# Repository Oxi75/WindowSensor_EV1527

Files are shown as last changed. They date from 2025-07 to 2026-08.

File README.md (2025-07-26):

# WindowSensor_EV1527

This project enables the integration of affordable 433 MHz window sensors and push buttons into the **homee** smart home system via **vhih**.

## Hardware

- **ESP32** microcontroller
- **EV1527** 433 MHz receiver module

## Features

- Receives signals from standard 433 MHz window sensors and push buttons (EV1527 protocol)
- Forwards sensor states to homee via vhih
- Simple configuration through a web interface

## Installation

1. Assemble the hardware according to the schematic (ESP32 + EV1527 receiver).
2. compile and flash the nano firmware [PlatformIO](https://platformio.org/).
3. compile and flash the ESP32 firmware 
4. Connect the device to Wi-Fi and configure it via the web interface.

## Directory Structure

- `src/` – Project source code
- `include/` – Header files
- `data/` – Web interface files (e.g., configuration)
- `examples/` – Example projects
- `doku/` – user manual
- `KiCad/` – Schematics and PCB layout

## Notes

- Further information about integrating with homee and vhih can be found in the documentation and source code.
- License: See [LICENSE](LICENSE)

---

Window and door sensor for homee, based on EV1527 and ESP32.

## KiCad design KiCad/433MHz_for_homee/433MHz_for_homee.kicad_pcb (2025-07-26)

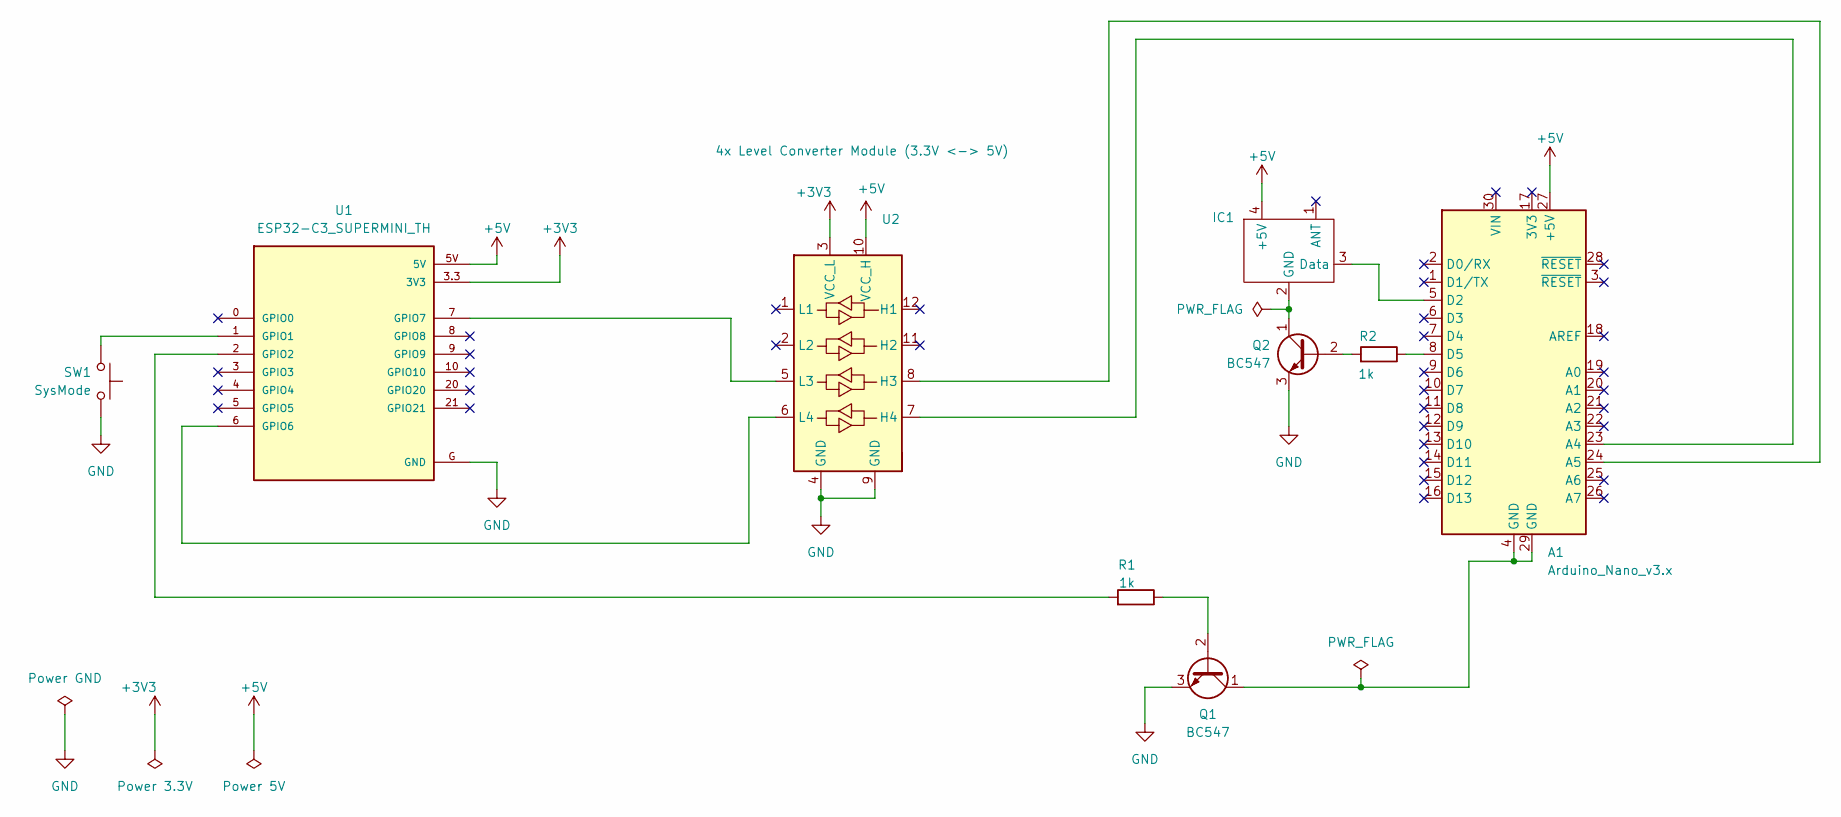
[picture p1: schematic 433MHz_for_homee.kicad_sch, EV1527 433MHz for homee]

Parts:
A1: Arduino_Nano_v3.x; Arduino_Nano
IC1: rxb14_433MHz_module
Q1, Q2: BC547; TO-92_Inline
R1, R2: 1k; R_0805_2012Metric_Pad1.20x1.40mm_HandSolder
SW1: SysMode; PinHeader_1x02_P2.54mm_Vertical
U1: ESP32-C3_SUPERMINI_TH; MODULE_ESP32-C3_SUPERMINI_TH
U2: 4x Level Converter Module (3.3V <-> 5V); LevelConverter_MH

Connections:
+3V3: U1.3.3 (3V3), U2.3 (VCC_L)
+5V: A1.27 (+5V), IC1.4 (+5V), U1.5V, U2.10 (VCC_H)
GND: Q1.3 (E), Q2.3 (E), SW1.1, U1.G (GND), U2.4 (GND), U2.9 (GND)
unnamed: A1.23 (A4), U2.7 (H4)
unnamed: A1.24 (A5), U2.8 (H3)
unnamed: A1.5 (D2), IC1.3 (Data)
unnamed: A1.8 (D5), R2.1
unnamed: IC1.2 (GND), Q2.1 (C)
unnamed: Q1.2 (B), R1.1
unnamed: A1.4 (GND), A1.29 (GND), Q1.1 (C)
unnamed: Q2.2 (B), R2.2
unnamed: SW1.2, U1.1 (GPIO1)
unnamed: R1.2, U1.2 (GPIO2)
unnamed: U1.6 (GPIO6), U2.6 (L4)
unnamed: U1.7 (GPIO7), U2.5 (L3)

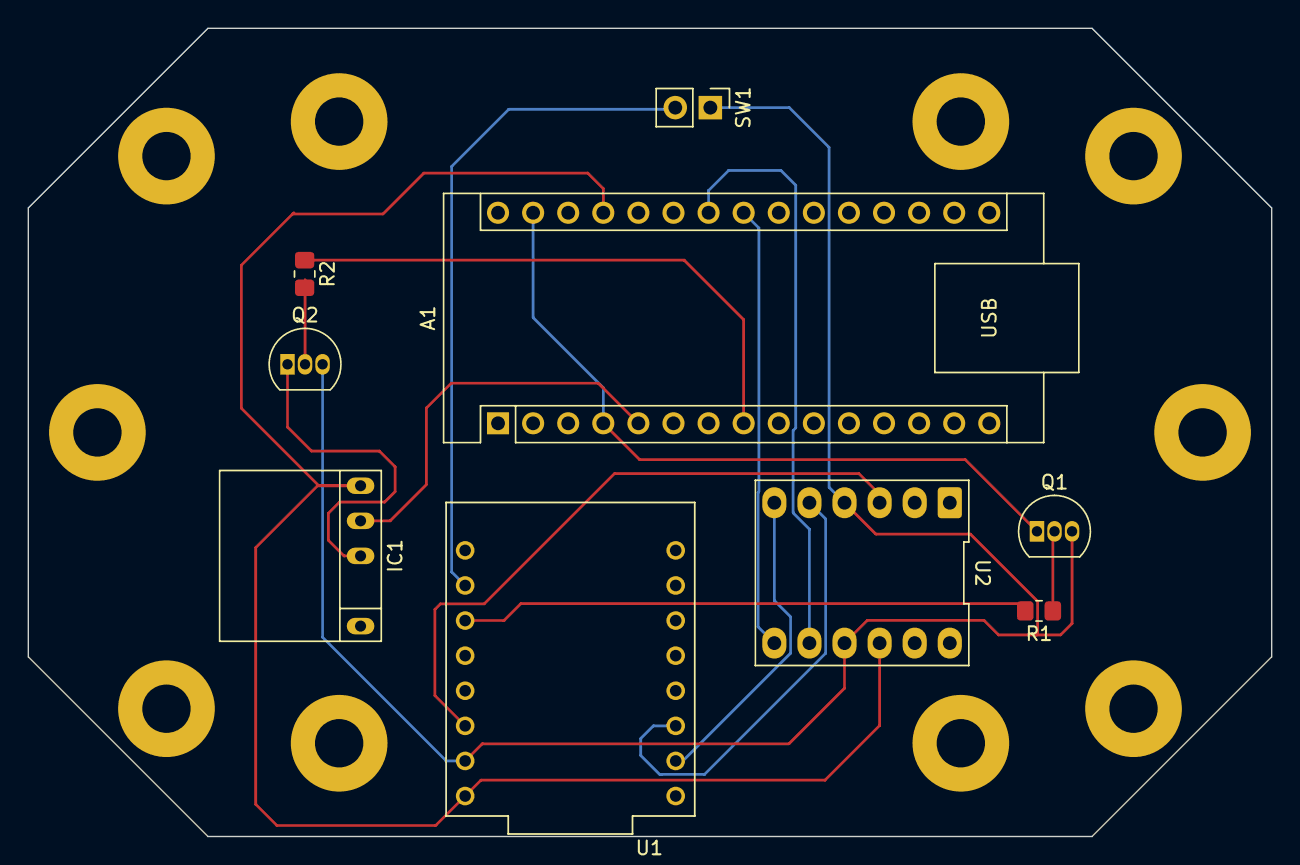
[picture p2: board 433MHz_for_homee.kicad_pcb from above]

Board: 2 copper layers, 90.0 x 58.5 mm, 9 parts (0 on the bottom side), 15 nets.

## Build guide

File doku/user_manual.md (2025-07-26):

# User Manual: Sensor\_EV1527

## 1. Hardware requirements
* Arduino Nano or similar
* ESP32-C3 or similar
* RBX14 433MHz Module
* 2x Level-Converter 3.3V <-> 5V
* 2x BC547
* 2x Resistor 1k
* Push-Button for System mode
* wire (17.3cm) or solid antenna suited for 433MHz
* sensors based on EV1527

 Note that the entire system will be supplied via the USB port of the ESP32. If you use the USB of the Nano it will not work. Only for flashing the Nano firmware you'll need the USB connector of the Nano.

## 2. Software requirements
* `visual studio code` + `platformIO`

### 2. Compiling and flashing
#### 2.1 Arduino firmware
Connect the Arduino via USB to your computer.
Modify the platformio.ini in the following way:  
    &nbsp;&nbsp;&nbsp;[platformio]  
    &nbsp;&nbsp;&nbsp;default_envs = nano  
    &nbsp;&nbsp;&nbsp;;default_envs = esp32-c3  

Build and upload the code.

#### 2.1 ESP32 firmware
Connect the ESP32 via USB to your computer.
Modify the platformio.ini in the following way:  
    &nbsp;&nbsp;&nbsp;[platformio]  
    &nbsp;&nbsp;&nbsp;;default_envs = nano  
    &nbsp;&nbsp;&nbsp;default_envs = esp32-c3  

Build and upload the code.

Upload config.html and index html:
execute `pio run --target uploadfs`in the platformio temrinal.

### 3. Configuration
#### 3.1 general setup
Note: On first startup a config.json file will be generated in the minifs of the ESP32.

Press the systemMode push button during boot of the ESP32 startup. The ESP will enter the setup mode and provides and Access point. 
This are the WiFi data:  
&nbsp;&nbsp;&nbsp;SSID: EV1527 for homee
&nbsp;&nbsp;&nbsp;Password: 12345678
&nbsp;&nbsp;&nbsp;IP: 192.168.4.1  
&nbsp;&nbsp;&nbsp;SubNet-Mask:  255.255.255.0
Note that the WiFi data for the access point cannot be changed!

After you have been connected to your access point you can connect to the WebInterface via your browser by entering http://192.168.4.1.  
It's recommended to use your PC browser since the WebInterface is not responsive and might be difficult to read on mobile devices.

You can enter now your personal WiFi data, configure the sensor address, ...
Be careful uploading html files and firmware. If your upload invalid files it might corrupt your ESP system and you have to flash it again.

#### 3.2 sensor configuration
You can configure up to 32 sensors.  
You must give a name to each sensor. Only use English letters (e.g. "Tuere" instead of "Türe"). Spaces are ok.  
Each sensor must have a unique homee-ID. Unique means in the entire homee-network.  
Each sensor has a unique address. You can get this address from the section `last received signal`. Let the sensor send its signal(s) and get the address and values from there.

Each sensor can be one of the four types:
1. OpenClose-Sensor
2. OneButton-Remote
3. TwoButton-Remote
4. ThreeButton-Remote
5. FourButton-Remote

For the OpenClose-Sensor you can configure a valaue for Open (Window / Door openes), for Close, for Modification Alarm and for a Battery Low warning. Set the Signal value to -1 if there is no such value available for your sensor model.
If you set a delay, the signal will be removed after the given time in seconds.

For the remote button sensors you have to define the following:  
* Value - the value of the sensor button
* Delay - when shall the system automatically switch back to "off"; -1 if the state shall remain
* Mode: - "Toggle" (usually in combination with delay -1); re-trigger (usually in combination with a delay > 0)  
toggle means that the state will remain until the button is pressed again or until the delay time is over  
re-trigger means that pressing the button will start the delay time again

### Screenshots

assebled PCB:
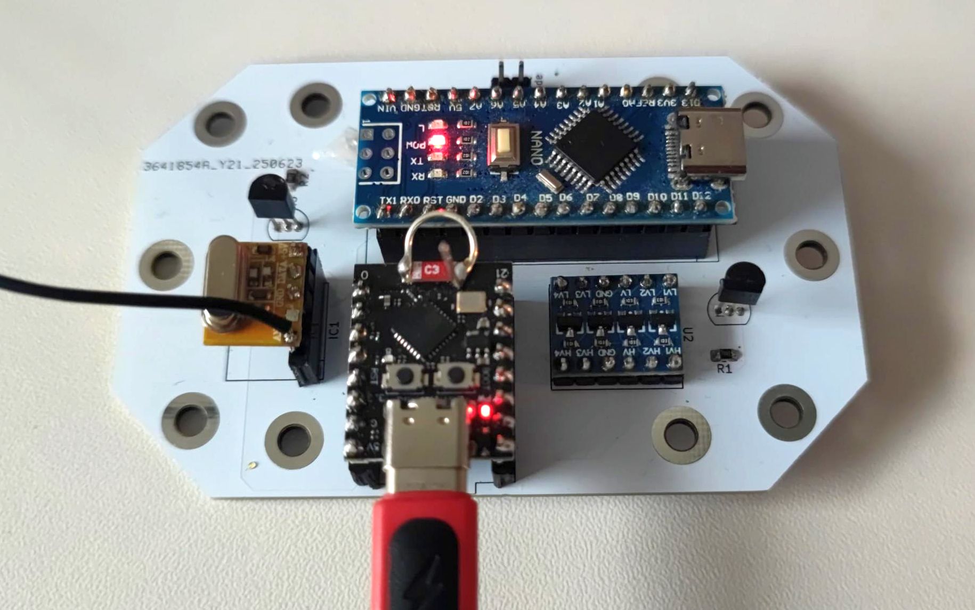
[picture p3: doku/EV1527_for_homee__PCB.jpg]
assebled PCB


fully integraged:
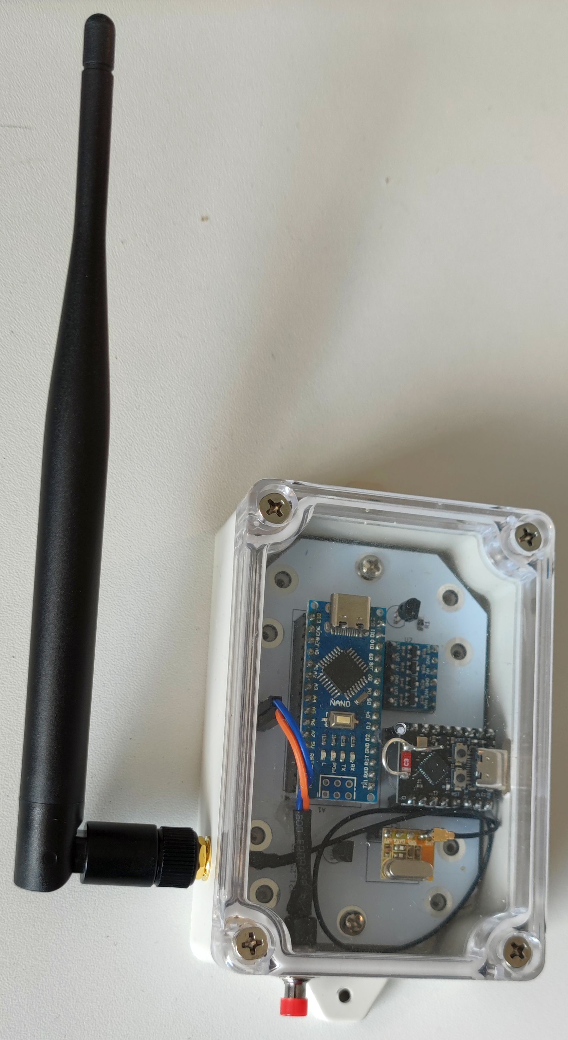
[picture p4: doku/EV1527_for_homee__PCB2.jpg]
fully integrated


used sensors:
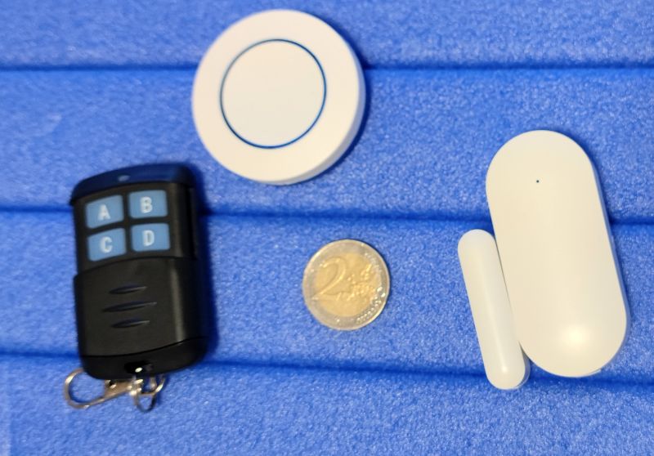
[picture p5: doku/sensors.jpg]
sensors
)

---

For updates and source code, refer to the [GitHub repository](https://github.com/Oxi75/WindowSensor_EV1527).

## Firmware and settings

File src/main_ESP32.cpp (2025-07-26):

/*
  EV1527 Window Sensor Monitor for homee
  
  This program monitors up to 32 window sensors based on the EV1527 chip
  and connects to the homee smart home system.
  The sensor signals are received via I2C and processed to update the homee nodes.
  
  Multiple operation modes:
  1. Configuration mode (AP mode for setup)
  2. Normal mode (sensor monitoring and homee integration)
  
  Hardware: ESP32-C3

  Libraries:
  - homee-api-esp32: https://github.com/Oxi75/homee-api-esp32
*/

#include "global_defines.h"
#include <Arduino.h>
#include <Update.h>
#include <WiFi.h>
#include <ESPAsyncWebServer.h>
#include <Wire.h>
#include <LittleFS.h>
#include "ConfigManager.h"
#include <string>
#include "virtualHomee.hpp"

#define RECEIVER_CHECK_INTERVAL 350             // Interval in ms to check for received signals

String FW_VERSION_STR = String(FW_VERSION_ESP, 2);

#define CANodeProfileOneButtonRemote 20
#define CANodeProfileTwoButtonRemote 24
#define CANodeProfileThreeButtonRemote 25
#define CANodeProfileFourButtonRemote 26

#define CANodeProfileOpenCloseSensor 2000
#define CAAttributeTypeOpenClose 14
#define CAAttributeTypeAlarm 108
#define CAAttributeTypeBatteryLowAlarm 69
#define CAAttributeTypeOnOff 1
#define CAAttributeTypeFirmwareRevision 44
#define CAAttributeTypeBinaryInput 19
#define CAAttributeTypeButtonState 40
#define CAAttributeTypeNone 0

#define AttrID_SnsAddr    0b00100000  //one part of the Attribute ID of homee, the other one is the sensor number
#define AttrID_FwRev      0b01000000  //one part of the Attribute ID of homee, the other one is the sensor number
#define AttrID_Sig1       0b01100000  //one part of the Attribute ID of homee, the other one is the sensor number
#define AttrID_Sig2       0b10000000  //one part of the Attribute ID of homee, the other one is the sensor number
#define AttrID_Sig3       0b10100000  //one part of the Attribute ID of homee, the other one is the sensor number
#define AttrID_Sig4       0b11000000  //one part of the Attribute ID of homee, the other one is the sensor number


const char* AP_SSID = "EV1527 for homee";
const char* AP_PASS = "12345678";
const IPAddress AP_IP(192, 168, 4, 1);
const IPAddress AP_SUBNET(255, 255, 255, 0);
bool isAPMode = false;

ConfigManager config;

// LED related functions
static unsigned long lastBlinkTime = 0;
static const unsigned long blinkInterval = 500; // 500ms Blink-Intervall
static bool ledState = false;

void LED_setup()
{
    pinMode(PIN_LED, OUTPUT);
    digitalWrite(PIN_LED, HIGH); // LED aus (meist ist LOW = an bei ESP8266)
}

void ledOn()
{
    digitalWrite(PIN_LED, LOW); // LED einschalten (LOW = an beim ESP8266)
    ledState = true; // LED-Status setzen
    lastBlinkTime = millis() - blinkInterval - 1; // Zeitstempel aktualisieren
}

void ledOff()
{
    digitalWrite(PIN_LED, HIGH); // LED ausschalten (HIGH = aus beim ESP8266)
    ledState = false; // LED-Status zurücksetzen
    lastBlinkTime = millis() - blinkInterval - 1; // Zeitstempel aktualisieren    
}

void ledToggle()
{
    ledState = !ledState;
    digitalWrite(PIN_LED, ledState ? LOW : HIGH); // LED umschalten
    lastBlinkTime = millis() - blinkInterval - 1; // Zeitstempel aktualisieren
}

void ledBlink()
{
    unsigned long currentMillis = millis();
    if (currentMillis - lastBlinkTime >= blinkInterval)
    {
        lastBlinkTime = currentMillis;
        ledState = !ledState;
        digitalWrite(PIN_LED, ledState ? LOW : HIGH); // LED umschalten
    }
}

//Sensor Daten
struct LastSignal
{
    String sensorAddress;
    String sensorData;
    String binary;
};

// Globale Variable mit dem letzten Signal
LastSignal lastSignal = {
    .sensorAddress = "-------",
    .sensorData = "-",
    .binary = "------------------------",
};
 

//WiFi realted functions
AsyncWebServer server(80);

unsigned long lastWifiCheckTime = 0;
const unsigned long wifiCheckInterval = 30000; // Alle 30 Sekunden WLAN prüfen
const unsigned long wifiMaxAttempts = 20; // 
static uint32_t wifiConnectAttempts = 0; // Anzahl der Versuche, sich mit dem WLAN zu verbinden
static bool WiFi_reconnect = false;  //system is in reconnection
String configBodyContent = "";  //variable to hold the HTML content of the config page

IPAddress IPAddressFromString(const String& str) {
  IPAddress ip;
  if (!ip.fromString(str)) {
    Serial.println("[IP] Invalid IP string: " + str);
    return IPAddress(0, 0, 0, 0);
  }
  return ip;
}

void startWiFi() 
{ 
  pinMode(PIN_SYSMODE, INPUT_PULLUP);
  isAPMode = digitalRead(PIN_SYSMODE) == LOW;

  if (isAPMode)
  {
    Serial.println("[BOOT] Starting in AccessPoint mode");
    WiFi.softAPConfig(AP_IP, AP_IP, AP_SUBNET);
    WiFi.softAP(AP_SSID, AP_PASS);
    Serial.println("[AP] SSID: " + String(AP_SSID));
    Serial.println("[AP] Password: " + String(AP_PASS));
    Serial.println("[AP] IP: " + WiFi.softAPIP().toString());
  }
  else
  {
    Serial.println("[BOOT] Starting in Standard mode");
    WiFi.config(
      IPAddressFromString(config.clientIP),
      IPAddressFromString(config.gatewayIP),
      IPAddressFromString(config.subnet)
    );
    WiFi.begin(config.ssid.c_str(), config.password.c_str());

    int retries = 0;
    while (WiFi.status() != WL_CONNECTED && retries < 20)
    {
      ledToggle(); // LED blinken lassen, um den Verbindungsversuch anzuzeigen
      delay(500);
      Serial.print(".");
      retries++;
    }

    if (WiFi.status() != WL_CONNECTED) {
      Serial.println("\n[WIFI] Connection failed. Restarting...");
      ESP.restart();
    }

    Serial.println("\n[WIFI] Connected. IP: " + WiFi.localIP().toString());
  }

  ledOn(); // alten Zustand der LED wiederherstellen
}


void WiFi_check(bool restart = true)
{
    if ((millis() - lastWifiCheckTime >= wifiCheckInterval) || (WiFi_reconnect))
    {
        lastWifiCheckTime = millis();
    
        // Bei Verbindungsverlust erneut verbinden
        if (WiFi.status() != WL_CONNECTED) 
        {
            WiFi_reconnect = true;
            Serial.println("WiFi connection lost. Reconnecting...");
            ledToggle(); // LED blinken lassen, um den Verbindungsverlust anzuzeigen
            WiFi.reconnect();
            wifiConnectAttempts++;
            delay(500);
         }

        if (WiFi.status() == WL_CONNECTED)
        {
            WiFi_reconnect = false;
            wifiConnectAttempts = 0; // WLAN-Verbindung erfolgreich
            ledOff(); // LED ausschalten, wenn WLAN verbunden ist
        }

        if (wifiConnectAttempts >= wifiMaxAttempts) 
        {
            Serial.println("Failed to reconnect to WiFi. Restarting ESP...");
            ESP.restart(); // ESP32 zurücksetzen, wenn keine Verbindung hergestellt werden kann
        }    
    }
}


// Homee related functions
virtualHomee vhih;

void homee_setup()
{
  for (int sns = 0; sns < MAX_SENSORS; sns++)
  {
    if ((config.sensors[sns].name == "") || (!config.sensors[sns].active) || (config.sensors[sns].homeeID == 0))
    {
      Serial.printf("[HOMEE] Sensor %d is not active or has no name or invalid homeeID -> skipping.\n", sns);      
      continue;
    }

    if ((config.RTData[sns].btnCnt > 4) || (config.RTData[sns].btnCnt < 1))
    {
      Serial.printf("[HOMEE] Sensor %d has invalid button count %d or an invalid type '%s' -> skipping.\n", sns, config.RTData[sns].btnCnt, config.sensors[sns].type.c_str());
      continue;
    }
/*
    if ((config.sensors[sns].type != "OpenClose Sensor") 
     && (config.sensors[sns].type != "OneButton Remote") && (config.sensors[sns].type != "TwoButton Remote")
     && (config.sensors[sns].type != "ThreeButton Remote") && (config.sensors[sns].type != "FourButton Remote"))
    {
      Serial.printf("[CONFIG] Sensor %d has an invalid type '%s' -> skipping.\n", sns, config.sensors[sns].type.c_str());
      continue;
    }
*/

    Serial.printf("[HOMEE] setup sensor %s with address 0x%05x as %s at homee device with ID %d\n", config.sensors[sns].name.c_str(), config.sensors[sns].address, config.sensors[sns].type.c_str(), config.sensors[sns].homeeID);

    //all checks done, now new add the new sensor with all its attributes to homee    
    node *n;
    nodeAttributes *na, *naAddr, *naFW;

    naAddr = new nodeAttributes(CAAttributeTypeNone);  //
    naAddr->setName("Sensor Address");
    naAddr->setId(AttrID_SnsAddr | sns);
    naAddr->setUnit("0x" + String(config.sensors[sns].address, HEX));  //set unit to the address in hex format
    naAddr->setMinimumValue(0);
    naAddr->setMaximumValue(999999999999); 
    naAddr->setCurrentValue(config.sensors[sns].address);
    naAddr->setEditable(false);
    naAddr->setCallback(nullptr);

    naFW = new nodeAttributes(CAAttributeTypeFirmwareRevision); 
    naFW->setName("Firmware Version");
    naFW->setId(AttrID_FwRev | sns); //unique ID for each sensor
    naFW->setUnit("");  
    naFW->setMinimumValue(0.0);
    naFW->setMaximumValue(1000.0); 
    naFW->setCurrentValue(FW_VERSION_ESP);
    naFW->setEditable(false);
    naFW->setCallback(nullptr);

    if (config.RTData[sns].OCSensor)
    {
      n = new node(config.sensors[sns].homeeID, CANodeProfileOpenCloseSensor, config.sensors[sns].name);     
      n->AddAttributes(naAddr);     //set attribute Sensor Address to node
      n->AddAttributes(naFW);       //set attribute Firmware to node

      //Attribut Status
      na = new nodeAttributes(CAAttributeTypeOpenClose);  //open / closed state
      na->setName("Status");
      na->setId(AttrID_Sig1 | sns); //unique ID for each sensor        
      na->setMinimumValue(0);
      na->setMaximumValue(1); 
      na->setCurrentValue(0);
      na->setCallback(nullptr);
      na->setEditable(false);
      n->AddAttributes(na);       //set attribute to node

      //Attribut Alarm
      na = new nodeAttributes(CAAttributeTypeAlarm);  //CAAttributeTypeAlarm
      na->setName("Alarm");
      na->setId(AttrID_Sig3 | sns);   //unique ID for each sensor
      na->setUnit("");  
      na->setMinimumValue(0);
      na->setMaximumValue(1); 
      na->setCurrentValue(0);     //default value
      na->setEditable(false);
      na->setCallback(nullptr);
      n->AddAttributes(na);       //set attribute to node

      //Attribut Batterie
      na = new nodeAttributes(CAAttributeTypeBatteryLowAlarm);
      na->setName("Battery Status");
      na->setId(AttrID_Sig4 | sns); //unique ID for each sensor
      na->setUnit("");
      na->setMinimumValue(0);  //0 = Battery OK, 1 = Battery low
      na->setMaximumValue(1); 
      na->setCurrentValue(0);  //default value
      na->setEditable(false);
      na->setCallback(nullptr);
      n->AddAttributes(na);       //set attribute to node
    }
    else  //must be an x-button remote
    {
      uint32_t vhihProfile = 0;
      if (config.RTData[sns].btnCnt == 1)  vhihProfile = CANodeProfileOneButtonRemote;
      else if (config.RTData[sns].btnCnt == 2) vhihProfile = CANodeProfileTwoButtonRemote;
      else if (config.RTData[sns].btnCnt == 3) vhihProfile = CANodeProfileThreeButtonRemote;
      else if (config.RTData[sns].btnCnt == 4) vhihProfile = CANodeProfileFourButtonRemote;

      n = new node(config.sensors[sns].homeeID, vhihProfile, config.sensors[sns].name);
      n->AddAttributes(naAddr);     //set attribute Sensor Address to node
      n->AddAttributes(naFW);       //set attribute Firmware to node


      //Attribut for first Button
      na = new nodeAttributes(CAAttributeTypeButtonState);  //open / closed state
      na->setName("Status Button1");
      na->setId(AttrID_Sig1 | sns); //unique ID for each sensor        
      na->setMinimumValue(0);
      na->setMaximumValue(1); 
      na->setCurrentValue(0);
      na->setCallback(nullptr);
      na->setEditable(false);
      n->AddAttributes(na);       //set attribute to node

      if (config.RTData[sns].btnCnt >= 2)
      {
        //Attribut Status Button2
        na = new nodeAttributes(CAAttributeTypeButtonState);  //open / closed state
        na->setName("Status Button2");
        na->setId(AttrID_Sig2 | sns); //unique ID for each sensor        
        na->setMinimumValue(0);
        na->setMaximumValue(1); 
        na->setCurrentValue(0);
        na->setCallback(nullptr);
        na->setEditable(false);
        n->AddAttributes(na);       //set attribute to node
      }


      if (config.RTData[sns].btnCnt >= 3)
      {
        //Attribut Status Button3
        na = new nodeAttributes(CAAttributeTypeButtonState);  //open / closed state
        na->setName("Status Button3");
        na->setId(AttrID_Sig3 | sns); //unique ID for each sensor        
        na->setMinimumValue(0);
        na->setMaximumValue(1); 
        na->setCurrentValue(0);
        na->setCallback(nullptr);
        na->setEditable(false);
        n->AddAttributes(na);       //set attribute to node
      }

      if (config.RTData[sns].btnCnt == 4)
      {
        //Attribut Status Button4
        na = new nodeAttributes(CAAttributeTypeButtonState);  //open / closed state
        na->setName("Status Button4");
        na->setId(AttrID_Sig4 | sns); //unique ID for each sensor        
        na->setMinimumValue(0);
        na->setMaximumValue(1); 
        na->setCurrentValue(0);
        na->setCallback(nullptr);
        na->setEditable(false);
        n->AddAttributes(na);       //set attribute to node
      }
    }

    vhih.addNode(n); //add the new node to homee
  }

  vhih.start();  //start homee API

  Serial.println("Homee configured");
  delay(1000);  
}


static double lastValue = 1;
void homee_updateValues(uint32_t snsNo)
{  
  Serial.printf("update homee values for Sensor No %d (%s)\n", snsNo, config.sensors[snsNo].type.c_str());

  nodeAttributes *na;
  
  if ((config.RTData[snsNo].btnCnt >= 4) && (config.RTData[snsNo].signal4))
  {
    na = vhih.getAttributeById(AttrID_Sig4 | snsNo);
    na->setCurrentValue(config.RTData[snsNo].signal4_val);
    config.RTData[snsNo].signal4 = false;
    if (na) vhih.updateAttributeValue(na, na->getCurrentValue());
    delay(200);
    yield();
  } 

  if ((config.RTData[snsNo].btnCnt >= 3) && (config.RTData[snsNo].signal3))
  {
    na = vhih.getAttributeById(AttrID_Sig3 | snsNo);
    na->setCurrentValue(config.RTData[snsNo].signal3_val);
    config.RTData[snsNo].signal3 = false;
    if (na) vhih.updateAttributeValue(na, na->getCurrentValue());
    delay(200);
    yield();
  } 

  if ((config.RTData[snsNo].btnCnt >= 2) && (config.RTData[snsNo].OCSensor == false) && (config.RTData[snsNo].signal2))
  {
    na = vhih.getAttributeById(AttrID_Sig2 | snsNo);
    na->setCurrentValue(config.RTData[snsNo].signal2_val);
    config.RTData[snsNo].signal2 = false;
    if (na) vhih.updateAttributeValue(na, na->getCurrentValue());
    delay(200);
    yield();
  } 

  if ((config.RTData[snsNo].btnCnt >= 1) && (config.RTData[snsNo].OCSensor == false) && (config.RTData[snsNo].signal1))
  {
    na = vhih.getAttributeById(AttrID_Sig1 | snsNo);
    na->setCurrentValue(config.RTData[snsNo].signal1_val);
    config.RTData[snsNo].signal1 = false;
    if (na) vhih.updateAttributeValue(na, na->getCurrentValue());
    delay(200);
    yield();
  } 

  if ((config.RTData[snsNo].OCSensor) && (config.RTData[snsNo].signal1))
  {
    na = vhih.getAttributeById(AttrID_Sig1 | snsNo);
    na->setCurrentValue(config.RTData[snsNo].signal1_val);
    config.RTData[snsNo].signal1 = false;
    if (na) vhih.updateAttributeValue(na, na->getCurrentValue());
    delay(200);
    yield();
  } 

} 





/// ****************************************************
/// @brief Check for received signals and update sensor data accordingly.
/// @param HomeeEnabled 
/// ****************************************************
void Receiver_setup()
{
  pinMode(PIN_RECEIVER_PWR, OUTPUT);    // set the receiver power pin as output
  digitalWrite(PIN_RECEIVER_PWR, LOW); // switch off the receiver power
  delay(500); // wait for the receiver to stabilize
  digitalWrite(PIN_RECEIVER_PWR, HIGH); // switch on the receiver power
  delay(2000); // wait for the receiver to stabilize

  Wire.begin(PIN_SDA, PIN_SCL);

  Serial.println("[Receiver] setup complete.");
}


// Signal related functions
uint32_t Receiver_getSignal()
{
  uint32_t sensorData = 0;

  Wire.requestFrom(I2C_SLAVE_ADDRESS, 4); //read 4 bytes from the I2C slave device

  if (Wire.available() >= 4)
  {
      sensorData  = Wire.read();
      sensorData |= Wire.read() << 8;
      sensorData |= Wire.read() << 16;
      sensorData |= Wire.read() << 24;        
  }
  else sensorData = DUMMY_CODE_E; // Rückgabe eines Dummy-Wertes, wenn nicht genügend Daten verfügbar sind

//  Serial.printf("Receiver_getSignal(): Received signal: 0x%08x\n", sensorData);

  return sensorData; 
}

void Receiver_check(bool HomeeEnabled)
{
  static bool firstCall = true;
  if (firstCall)
  {
    Serial.print("Receiver_check() for the first time.");
    if (HomeeEnabled) Serial.println(" Homee is enabled.");
    else Serial.println(" Homee is disabled.");
    firstCall = false;
  }

  uint32_t snsAddr = 0;       
  uint32_t snsValue = 0;
  uint32_t now = millis();    // current timestamp
  bool validSignal = false;   // Flag to check if a valid signal was received

  uint32_t sensorData = Receiver_getSignal(); // Lese die Signaldaten von Arduino
  
//  if (sensorData == DUMMY_CODE_F) Serial.println("Receiver_check(): Watchdog-Signal received, no sensor data available.");
//  else if (sensorData == DUMMY_CODE_0) Serial.println("Receiver_check(): FiFo empty, no sensor data available.");
//  else Serial.printf("Receiver_check(): Received signal: 0x%08x\n", sensorData);
  now = millis();                                     // update the timestamp of the last received, valid signal

  if (((sensorData != DUMMY_CODE_0) && (sensorData != DUMMY_CODE_F) && (sensorData != DUMMY_CODE_E)))
  {
    ledOn();                                            // Switch on the LED to indicate signal reception
    validSignal = true;                                 // signal is valid, so set the flag to true

    lastSignal.binary = String(sensorData, BIN);        // convert the sensor data to binary string

    snsValue = sensorData & 0x000000F;                  // ectract the lower 4 bit as value
    lastSignal.sensorData = String(snsValue, DEC);      

    snsAddr = (sensorData >> 4) & 0xFFFFF;              // extract the sensor address from the upper 20 bits
    lastSignal.sensorAddress = String(snsAddr, HEX);    
    lastSignal.sensorAddress.toUpperCase();
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
void loop()
{ 
  static bool firstCall = true;
  if (firstCall)
  {
    Serial.println("Enter control loop for the first time.");
    firstCall = false;
  }

  if (!isAPMode) WiFi_check();

  if ( millis() - lastReceiverCheck >= RECEIVER_CHECK_INTERVAL) // Check receiver every 100ms
  {
//    Receiver_check(!isAPMode); // Check for received signals and update sensor data
    Receiver_check(true); // Check for received signals and update sensor data
    lastReceiverCheck = millis(); // Update the last check time
  }

  yield();  //delay is not allowed here, because homee connection would become unstable
}

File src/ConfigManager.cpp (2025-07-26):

#include "ConfigManager.h"
#include <LittleFS.h>
#include <ArduinoJson.h>

ConfigManager::ConfigManager()
{
  uint32_t now = millis();

  for (uint32_t i = 0; i < MAX_SENSORS; i++)
  {
    RTData[i].signal1_TS = now - 5000; // Set initial timestamps to 5 seconds ago
    RTData[i].signal2_TS = now - 5000; // Set initial timestamps to 5 seconds ago 
    RTData[i].signal3_TS = now - 5000; // Set initial timestamps to 5 seconds ago
    RTData[i].signal4_TS = now - 5000; // Set initial timestamps to 5 seconds ago
    RTData[i].signal1 = false; // Initialize signal1 to false
    RTData[i].signal2 = false; // Initialize signal2 to false
    RTData[i].signal3 = false; // Initialize signal3 to false
    RTData[i].signal4 = false; // Initialize signal4 to false
  }
}

bool ConfigManager::load()
{
  if (!LittleFS.exists(CONFIG_FILE)) {
    Serial.println("[CONFIG] config.json missing – using defaults");
    return false;
  }

  File f = LittleFS.open(CONFIG_FILE, "r");
  if (!f) return false;

  DynamicJsonDocument doc(16384);
  DeserializationError err = deserializeJson(doc, f);
  f.close();
  if (err) {
    Serial.println("[CONFIG] Parse error – using defaults");
    return false;
  }

  cfgInSTA = doc["system"]["cfgInSTA"] | false;
  cfgInStandardMode = doc["system"]["cfgInStandardMode"] | false;  
  ssid     = doc["wifi"]["ssid"] | "";
  password = decrypt(doc["wifi"]["pwX"] | "");
  clientIP  = doc["wifi"]["ip"] | "192.168.1.100";
  gatewayIP  = doc["wifi"]["gw"] | "192.168.1.1";
  subnet   = doc["wifi"]["mask"] | "255.255.255.0";

  JsonArray arr = doc["sensors"].as<JsonArray>();
  int i = 0;
  for (JsonObject s : arr)
  {
    if (i >= MAX_SENSORS) break;
    sensors[i].active   = s["active"] | false;
    sensors[i].name     = s["name"] | "";
    sensors[i].homeeID  = s["homeeID"] | 0;
    sensors[i].type     = s["type"] | "OpenClose";
    sensors[i].address  = s["address"] | 0;
    
    // Load new signal configuration
    sensors[i].signal1  = s["signal1"] | 0;
    sensors[i].signal2  = s["signal2"] | 0;
    sensors[i].signal3  = s["signal3"] | 0;
    sensors[i].signal4  = s["signal4"] | 0;

    // Load new mode configuration
    sensors[i].toggle1 = s.containsKey("toggle1") ? s["toggle1"] | true : true; // Default to true if not present
    sensors[i].toggle2 = s.containsKey("toggle2") ? s["toggle2"] | true : true; // Default to true if not present
    sensors[i].toggle3 = s.containsKey("toggle3") ? s["toggle3"] | true : true; // Default to true if not present
    sensors[i].toggle4 = s.containsKey("toggle4") ? s["toggle4"] | true : true; // Default to true if not present    

    // Load delay configuration - handle NaN values properly
    if (s.containsKey("delay1") && !s["delay1"].isNull()) {
      sensors[i].delay1 = s["delay1"];
    } else {
      sensors[i].delay1 = NAN;
    }
    if (s.containsKey("delay2") && !s["delay2"].isNull()) {
      sensors[i].delay2 = s["delay2"];
    } else {
      sensors[i].delay2 = NAN;
    }
    if (s.containsKey("delay3") && !s["delay3"].isNull()) {
      sensors[i].delay3 = s["delay3"];
    } else {
      sensors[i].delay3 = NAN;
    }
    if (s.containsKey("delay4") && !s["delay4"].isNull()) {
      sensors[i].delay4 = s["delay4"];
    } else {
      sensors[i].delay4 = NAN;
    }   
    
    RTData[i].OCSensor = false;
    if (sensors[i].type == "OpenClose Sensor")
    {
      RTData[i].OCSensor = true; // Mark as Open/Close Sensor
      RTData[i].btnCnt = 4;
    }     
    else if (sensors[i].type == "FourButton Remote") RTData[i].btnCnt = 4; // Four buttons
    else if (sensors[i].type == "ThreeButton Remote") RTData[i].btnCnt = 3; // Three buttons
    else if (sensors[i].type == "TwoButton Remote") RTData[i].btnCnt = 2; // Two buttons
    else if (sensors[i].type == "OneButton Remote") RTData[i].btnCnt = 1; // One button
    else RTData[i].btnCnt = 0; // Unknown type, no buttons

    i++;
  }

  for (int j = i; j < MAX_SENSORS; j++)
  {
    Serial.println("[CONFIG] No sensors in config. Setting defaults.");
    sensors[j].active = j == 0; // Only the first sensor is active by default
    sensors[j].name = "DefaultSensor";
    sensors[j].homeeID = 1;
    sensors[j].type = "OpenClose";
    sensors[j].address = 0;
    sensors[j].signal1 = 9999;
    sensors[j].signal2 = 9999;
    sensors[j].signal3 = 9999;
    sensors[j].signal4 = 9999;
    sensors[j].delay1 = NAN;
    sensors[j].delay2 = NAN;
    sensors[j].delay3 = NAN;
    sensors[j].delay4 = NAN;    
    sensors[j].toggle1 = true; // Default toggle for signal1
    sensors[j].toggle2 = true; // Default toggle for signal2
    sensors[j].toggle3 = true; // Default toggle for signal3
    sensors[j].toggle4 = true; // Default toggle for signal4
  }
  

  Serial.println("[CONFIG] Configuration loaded.");
  return true;
}
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

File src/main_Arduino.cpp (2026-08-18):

/*
  EV1527 Window Sensor Monitor for homee
  
  This program monitors signals coming from an EV1527 chip, filters them and sends them via I2C to a slave device.
  It can handle multiple sensors and supports a FIFO buffer to manage incoming signals.
  
  Hardware: Arduino Nano with 433 MHz receiver module (rbx14 or similar)

  Libraries:
  - RCSwitch: https://github.com/sui77/rc-switch/
*/


#include <Arduino.h>
#include <RCSwitch.h>
#include <Wire.h>
#include "global_defines.h"

#define DIN_RECEIVER        2           // interrupt pin for 433 MHz receiver
#define DOUT_POWER          5           // pin to control power for receiver module

#ifdef DEBUG
    #define FILTER_TIME_MS      1000     // duplicate filter timeout
#else
    #define FILTER_TIME_MS      300     // duplicate filter timeout
#endif    

#define MAX_PAUSE_INTERVAL  10000       // dummy code timeout

#define FIFO_SIZE 32                    // max buffered codes

RCSwitch mySwitch = RCSwitch();

// FIFO ring buffer
unsigned long fifoBuffer[FIFO_SIZE];
uint8_t fifoHead = 0;
uint8_t fifoTail = 0;

unsigned long lastReceivedCode = 0;
unsigned long lastReceivedTime = 0;

// ===== FIFO functions =====

bool fifoIsEmpty()
{
    return fifoHead == fifoTail;
}

bool fifoIsFull()
{
    return ((fifoHead + 1) % FIFO_SIZE) == fifoTail;
}

void fifoPush(unsigned long value)
{
    if (fifoIsFull())
    {
        fifoTail = (fifoTail + 1) % FIFO_SIZE;  // drop oldest
#ifdef DEBUG
        Serial.println("FIFO full -> oldest code dropped");
#endif
    }

    fifoBuffer[fifoHead] = value;
    fifoHead = (fifoHead + 1) % FIFO_SIZE;

#ifdef DEBUG
    Serial.print("Code queued: ");
    Serial.println(value, HEX);
#endif
}

unsigned long fifoPop()
{
    if (fifoIsEmpty()) return DUMMY_CODE_0; // return dummy code if empty

    unsigned long value = fifoBuffer[fifoTail];
    fifoTail = (fifoTail + 1) % FIFO_SIZE;
    return value;
}

// ===== I2C request handler =====

void requestEvent()
{
    unsigned long codeToSend = fifoPop();
    Wire.write((uint8_t *)&codeToSend, sizeof(codeToSend));
#ifdef DEBUG
    Serial.print("I2C request -> sent code: ");
    Serial.println(codeToSend, HEX);
#endif
}

// ===== Setup =====

void setup()
{
    Serial.begin(9600);
    Serial.println("******************************************");
    Serial.println("***    RC Receiver       " + String(FW_VERSION_ARDUINO, 2) + "          ***");
    Serial.println("******************************************");

    Wire.begin(I2C_SLAVE_ADDRESS);  // Initialize I2C as slave with specified address
    Wire.onRequest(requestEvent);   // Register request handler

    Serial.println("433MHz module power on sequence started (off (500ms) -> on)");
    pinMode(LED_BUILTIN, OUTPUT);
    digitalWrite(LED_BUILTIN, LOW); // turn off built-in LED to indicate power off

    pinMode(DOUT_POWER, OUTPUT);
    digitalWrite(DOUT_POWER, LOW);

    delay(500);
    digitalWrite(DOUT_POWER, HIGH);
    digitalWrite(LED_BUILTIN, HIGH); // turn on built-in LED to indicate power on
    delay(500);
    digitalWrite(LED_BUILTIN, LOW); // turn off built-in LED - standard mode

    mySwitch.enableReceive(digitalPinToInterrupt(DIN_RECEIVER));
}

// ===== Main loop =====

void loop()
{
    static bool firstRun = true;
    if (firstRun)
    {
        firstRun = false;
        Serial.println("Loop() started, waiting for codes...");
#ifndef DEBUG
        Serial.println("Note: Debug-Mode disabled, codes will not be printed here!");
#endif
    }

    unsigned long now = millis();

    if (mySwitch.available())
    {
        unsigned long code = mySwitch.getReceivedValue();

        // Visualize every decoded frame (even filtered duplicates) by toggling
        // the built-in LED, so reception can be checked without serial access.
        digitalWrite(LED_BUILTIN, !digitalRead(LED_BUILTIN));

        if ((code != lastReceivedCode) || (now - lastReceivedTime) > FILTER_TIME_MS)
        {   
            fifoPush(code);
            lastReceivedCode = code;
#ifndef DEBUG
            Serial.print(".");
#endif            
        }
#ifdef DEBUG
        else
        {
            Serial.print("Filtered duplicate code: ");
            Serial.println(code, HEX);
        }
#endif

        lastReceivedTime = now;
        mySwitch.resetAvailable();
    }

    // Insert dummy code after long pause
    if ((now - lastReceivedTime >= MAX_PAUSE_INTERVAL) && !fifoIsFull())
    {
#ifdef DEBUG
        Serial.println("No activity -> insert dummy code");
#endif
        fifoPush(DUMMY_CODE_F); // dummy code
        lastReceivedTime = now; 
        lastReceivedCode = DUMMY_CODE_F; // reset last received code
    }
}

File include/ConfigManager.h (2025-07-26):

#pragma once
#include <Arduino.h>

#define CONFIG_FILE "/config.json"
#define MAX_SENSORS 32
#define XOR_KEY 0xA5

struct SensorConfig
{
  bool active = false;
  uint16_t homeeID = 0;
  String type;
  String name;
  uint32_t address = 0x0;

  // Signal values for the different sensor types
  int32_t signal1 = -1;     // Push Button 1 / Open
  int32_t signal2 = -1;     // Push Button 2 / Close
  int32_t signal3 = -1;     // Push Button 3 / Alarm
  int32_t signal4 = -1;     // Push Button 4 / Battery

  bool toggle1 = true; // Toggle for signal1 (true = toggle, false = re-trigger)
  bool toggle2 = true; // Toggle for signal2 (true = toggle, false = re-trigger)
  bool toggle3 = true; // Toggle for signal2 (true = toggle, false = re-trigger)
  bool toggle4 = true; // Toggle for signal2 (true = toggle, false = re-trigger)
  
  // Auto-release delays in seconds (double to support fractional seconds)
  double delay1 = NAN;      // Delay for signal1 (NaN = no auto-release)
  double delay2 = NAN;      // Delay for signal2 (NaN = no auto-release)
  double delay3 = NAN;      // Delay for signal3 (NaN = no auto-release)
  double delay4 = NAN;      // Delay for signal4 (NaN = no auto-release)
};


struct SensorRuntimeData
{
  uint8_t btnCnt = 0; // Number of buttons (1-4)
  bool OCSensor = false; // Is this an Open/Close Sensor?
  
  bool signal1 = false; // Push/Button1 signal
  bool signal2 = false; // Release/Button2 signal
  bool signal3 = false; // Alarm/Button3 signal
  bool signal4 = false; // Battery/Button4 signal

  double signal1_val = 0.0; // Push/Button1 value
  double signal2_val = 0.0; // Release/Button2 value
  double signal3_val = 0.0; // Alarm/Button3 value
  double signal4_val = 0.0; // Battery/Button4 value

  double signal1_TS = 0;      // Timestamp of last signal1
  double signal2_TS = 0;      // Timestamp of last signal2 
  double signal3_TS = 0;      // Timestamp of last signal3
  double signal4_TS = 0;      // Timestamp of last signal4
};


class ConfigManager
{
public:
  ConfigManager();

  bool cfgInSTA = false;
  bool cfgInStandardMode = false;     // neue Checkbox „Enable configuration in standard mode"

  String ssid;
  String password;
  String clientIP;
  String gatewayIP;
  String subnet;

  
  SensorConfig sensors[MAX_SENSORS];
  SensorRuntimeData RTData[MAX_SENSORS];

  bool load();
  bool save();

  static String encrypt(String raw);
  static String decrypt(String enc);
};

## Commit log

2025-06-05 compiles again and receives transmissions from the sensor. Config part needs to be adapted and homee to be tested
2025-06-05 config saving still not correct
    [ConfigManager.cpp, main.cpp]
2025-06-06 improved signal-reset by timestamp but probably added some new issues
    [ConfigManager.h, main.cpp]
2025-06-11 - power cycle of receiver module on startup - modified processing of received signals
2025-06-12 GPIO changed, Webserver only in APMode, explicit reset of singnal attributes -> works better but still not stable
    [main.cpp]
2025-06-18 improved debugging on Arduino-Side + debugging deaktivated prepared power on for Arduino on ESP side
2025-06-18 ESP32 updated, compiles but not yet tested
2025-06-19 Arduino: fixed timing for debug mode on / off ESP32: limited I2C requests to less than 4times per sec
    [main_Arduino.cpp, main_ESP32.cpp]
2025-06-19 configuration works, receiving works, transmission to ESP works, Sensors and signals are detected properly, auto-release works
2025-06-20 modifictions in platformio.ini and related defines to support ESP32-C3-SuperMini Board
2025-06-22 KiCAD Project added
    [433MHz_for_homee.kicad_pcb, 433MHz_for_homee.kicad_sch]
2025-06-27 fixed an issue that prevents saving more then four sensor configurations
    [main_ESP32.cpp]
2025-06-30 fixed button colors on web interface
2025-06-30 fixed issues with download / upload index.html
    [main_ESP32.cpp]
2025-07-06 Revert "moved #debug to global defines"
    This reverts commit b1c320d95064f0c7cb145d6277651185ba752029.
    [ConfigManager.cpp, ConfigManager.h, main_ESP32.cpp]
2025-07-07 fixed some JSON issues
    [ConfigManager.cpp, main_ESP32.cpp]
2025-07-07 fixed a JSON size bug
    [main_ESP32.cpp]
2025-07-07 fixed a bug in the PCB
    [433MHz_for_homee.kicad_pcb, 433MHz_for_homee.kicad_sch]
2025-07-17 changed battery level to battery alarm for OpenClose-Sensors.
2025-07-20 added additional attribute that shows the sensor address in homee
2025-07-26 fixed some addressing bugs
    [main_ESP32.cpp]
2025-07-26 User manual updated
    [433MHz_for_homee.kicad_pcb, 433MHz_for_homee.kicad_sch]
2026-08-18 added more optical (LED) feedback to Arduino-Code
